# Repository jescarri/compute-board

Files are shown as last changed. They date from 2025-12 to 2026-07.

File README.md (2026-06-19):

# compute-board

This project is part of a template ecosystem for generating add-ons for my
custom esp32-powered compute boards.

It expects a 4-layer PCB with controlled impedance to 50 ohms.

<!-- KICAD_CI:START - Do not edit; auto-generated by .github/workflows/kicad-ci.yml -->



### Board preview

| Top | Bottom |
|---|---|
| top | bottom |

- [Schematic (PDF)](https://jescarri.github.io/compute-board/main/schematic/)
- [PCB layers (PDF)](https://jescarri.github.io/compute-board/main/pcb/)
- [STEP file](https://jescarri.github.io/compute-board/main/)
- [Full preview site](https://jescarri.github.io/compute-board/main/)

_Last updated from commit `0503de4` on 2026-06-19._
<!-- KICAD_CI:END -->

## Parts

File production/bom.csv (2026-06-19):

Designator | Footprint | Quantity | Value | LCSC Part #
C1 | 1206 | 1 | 100nF
C10, C11 | 1206 | 2 | 2.2uF
C2 | CP_EIA-3528-21_Kemet-B_HandSolder | 1 | 22uF
C3, C6 | 1206 | 2 | 10uF
C4, C8 | 1206 | 2 | 4.7uF
C5, C7 | 1206 | 2 | 1uF
C9 | 1206 | 1 | 0.1uF
D1 | LED_WS2812B-2020_PLCC4_2.0x2.0mm | 1 | WS2812B-2020
J1 | RHDR40W66P254_2X20_5146X500X1105P | 1 | PC104
J2 | TestPoint_Pad_2.0x2.0mm | 1 | ESP_PROG
J3 | JST_XH_B4B-XH-AM_1x04_P2.50mm_Vertical | 1 | ESP_PROGRAM
J4 | JST_XH_B4B-XH-AM_1x04_P2.50mm_Vertical | 1 | i2c
J5 | 1040310811 | 1 | 104031-0811
J6 | TestPoint_Pad_2.0x2.0mm | 1 | RST
R1, R2, R3, R4 | 1206 | 4 | 50k
R5, R6 | 1206 | 2 | 2.2K
R7, R8 | 1206 | 2 | 10K
RESET1 | SW_Push_1P1T_XKB_TS-1187A | 1 | RESET
SW1 | SW_Push_1P1T_XKB_TS-1187A | 1 | ESP Program
SW2 | SW_Push_1P1T_XKB_TS-1187A | 1 | WEB_CONF
U1 | ESP32-WROOM-32D | 1 | ESP32-WROOM-32E
U2, U4 | SOT-23-5 | 2 | XC6220B331MR
U3 | SOT-23 | 1 | TPS3839DBZ
V_BAT1 | Altech_AK300_1x02_P5.00mm_45-Degree | 1 | Conn_01x02

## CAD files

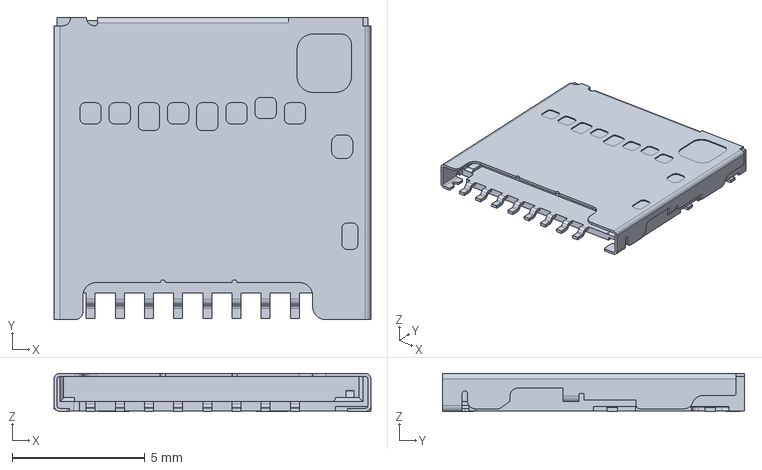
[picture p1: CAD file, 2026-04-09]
parts/3D/104031-0811.stp
11.9 x 11.4 x 1.45 mm

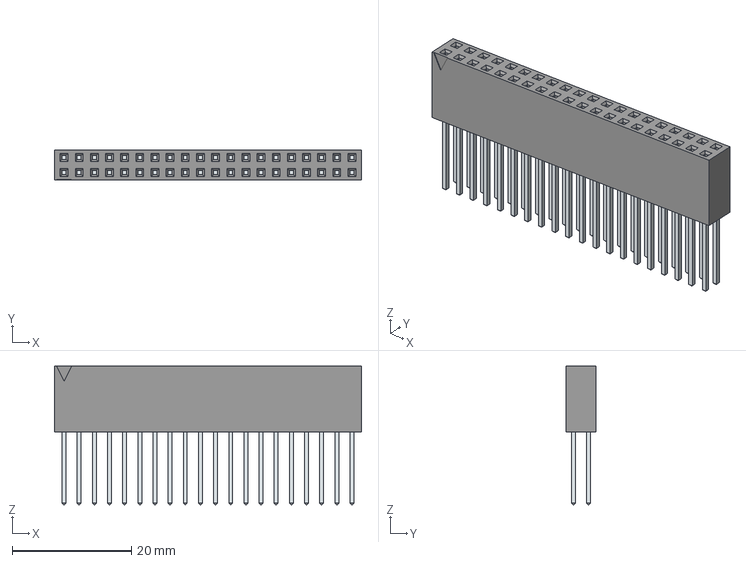
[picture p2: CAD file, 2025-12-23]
parts/3D/M20-6102045.stp
51.5 x 5.00 x 23.2 mm
LeadsArray

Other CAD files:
parts/3D/M20-6102045.stl

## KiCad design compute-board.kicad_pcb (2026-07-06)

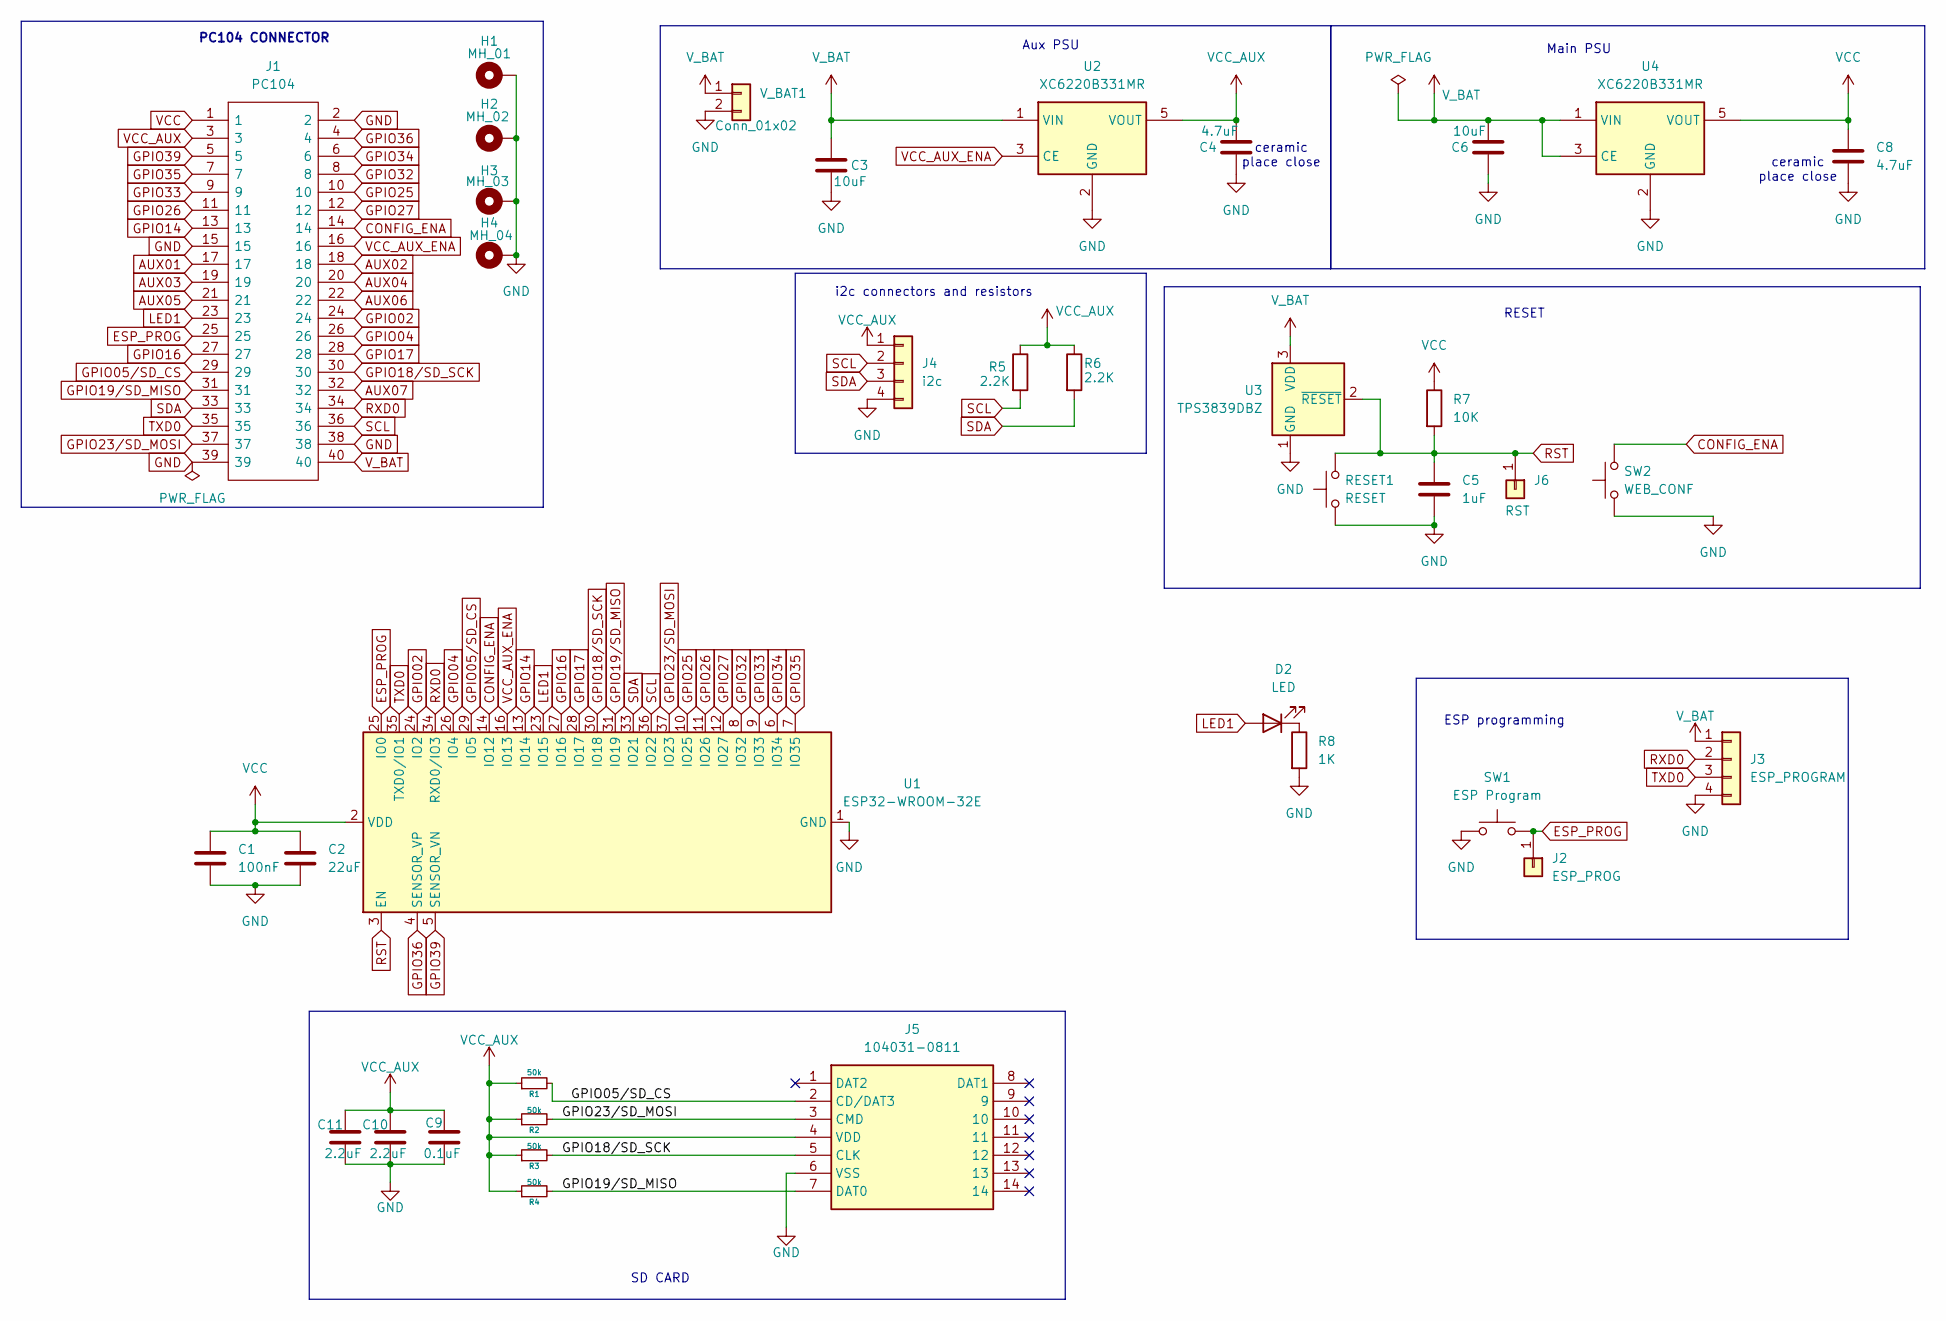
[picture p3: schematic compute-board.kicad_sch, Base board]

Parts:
C1: 100nF; C_1206_3216Metric_Pad1.33x1.80mm_HandSolder
C2: 22uF; CP_EIA-3528-21_Kemet-B_HandSolder
C3, C6: 10uF; C_1206_3216Metric_Pad1.33x1.80mm_HandSolder
C4, C8: 4.7uF; C_1206_3216Metric_Pad1.33x1.80mm_HandSolder
C5: 1uF; C_1206_3216Metric_Pad1.33x1.80mm_HandSolder
C9: 0.1uF; C_1206_3216Metric_Pad1.33x1.80mm_HandSolder
C10, C11: 2.2uF; C_1206_3216Metric_Pad1.33x1.80mm_HandSolder
D2: LED; LED_0603_1608Metric_Pad1.05x0.95mm_HandSolder
H1: MH_01; MountingHole_3.2mm_M3_ISO7380_Pad_TopBottom
H2: MH_02; MountingHole_3.2mm_M3_ISO7380_Pad_TopBottom
H3: MH_03; MountingHole_3.2mm_M3_ISO7380_Pad_TopBottom
H4: MH_04; MountingHole_3.2mm_M3_ISO7380_Pad_TopBottom
J1: PC104; RHDR40W66P254_2X20_5146X500X1105P; Manufacturer_Part_Number M20-6102045; Mouser Part Number 855-M20-6102045
J2: ESP_PROG; TestPoint_Pad_2.0x2.0mm
J3: ESP_PROGRAM; JST_XH_B4B-XH-AM_1x04_P2.50mm_Vertical
J4: i2c; JST_XH_B4B-XH-AM_1x04_P2.50mm_Vertical
J5: 104031-0811; 1040310811; Mouser Part Number 538-104031-0811
J6: RST; TestPoint_Pad_2.0x2.0mm
R1, R2, R3, R4: 50k; R_1206_3216Metric_Pad1.30x1.75mm_HandSolder
R5, R6: 2.2K; R_1206_3216Metric_Pad1.30x1.75mm_HandSolder
R7: 10K; R_1206_3216Metric_Pad1.30x1.75mm_HandSolder
R8: 1K; R_1206_3216Metric_Pad1.30x1.75mm_HandSolder
RESET1: RESET; SW_Push_1P1T_XKB_TS-1187A
SW1: ESP Program; SW_Push_1P1T_XKB_TS-1187A
SW2: WEB_CONF; SW_Push_1P1T_XKB_TS-1187A
U1: ESP32-WROOM-32E; ESP32-WROOM-32D
U2, U4: XC6220B331MR; SOT-23-5
U3: TPS3839DBZ; SOT-23
V_BAT1: Conn_01x02; Altech_AK300_1x02_P5.00mm_45-Degree

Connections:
AUX01: J1.17
AUX02: J1.18
AUX03: J1.19
AUX04: J1.20
AUX05: J1.21
AUX06: J1.22
AUX07: J1.32
CONFIG_ENA: J1.14, SW2.2, U1.14 (IO12)
ESP_PROG: J1.25, J2.1, SW1.2, U1.25 (IO0)
GND: C1.2, C2.2, C3.1, C4.2, C5.2, C6.2, C8.2, C9.2, C10.2, C11.2, H1.1, H2.1, H3.1, H4.1, J1.2, J1.15, J1.38, J1.39, J3.4, J4.4, J5.6 (VSS), R8.2, RESET1.1, SW1.1, SW2.1, U1.1 (GND), U1.15 (GND), U1.38 (GND), U1.39 (GND), U2.2 (GND), U3.1 (GND), U4.2 (GND), V_BAT1.2
GPIO02: J1.24, U1.24 (IO2)
GPIO04: J1.26, U1.26 (IO4)
GPIO05/SD_CS: J1.29, J5.2 (CD/DAT3), R1.2, U1.29 (IO5)
GPIO14: J1.13, U1.13 (IO14)
GPIO16: J1.27, U1.27 (IO16)
GPIO17: J1.28, U1.28 (IO17)
GPIO18/SD_SCK: J1.30, J5.5 (CLK), R3.2, U1.30 (IO18)
GPIO19/SD_MISO: J1.31, J5.7 (DAT0), R4.2, U1.31 (IO19)
GPIO23/SD_MOSI: J1.37, J5.3 (CMD), R2.2, U1.37 (IO23)
GPIO25: J1.10, U1.10 (IO25)
GPIO26: J1.11, U1.11 (IO26)
GPIO27: J1.12, U1.12 (IO27)
GPIO32: J1.8, U1.8 (IO32)
GPIO33: J1.9, U1.9 (IO33)
GPIO34: J1.6, U1.6 (IO34)
GPIO35: J1.7, U1.7 (IO35)
GPIO36: J1.4, U1.4 (SENSOR_VP)
GPIO39: J1.5, U1.5 (SENSOR_VN)
LED1: D2.2 (A), J1.23, U1.23 (IO15)
unnamed: D2.1 (K), R8.1
RST: C5.1, J6.1, R7.2, RESET1.2, U1.3 (EN), U3.2 (~RESET)
RXD0: J1.34, J3.2, U1.34 (RXD0/IO3)
SCL: J1.36, J4.2, R5.2, U1.36 (IO22)
SDA: J1.33, J4.3, R6.2, U1.33 (IO21)
TXD0: J1.35, J3.3, U1.35 (TXD0/IO1)
VCC: C1.1, C2.1, C8.1, J1.1, R7.1, U1.2 (VDD), U4.5 (VOUT)
VCC_AUX: C4.1, C9.1, C10.1, C11.1, J1.3, J4.1, J5.4 (VDD), R1.1, R2.1, R3.1, R4.1, R5.1, R6.1, U2.5 (VOUT)
VCC_AUX_ENA: J1.16, U1.16 (IO13), U2.3 (CE)
V_BAT: C3.2, C6.1, J1.40, J3.1, U2.1 (VIN), U3.3 (VDD), U4.1 (VIN), U4.3 (CE), V_BAT1.1

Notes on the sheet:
PC104 CONNECTOR
SD CARD
ceramic place close
ESP programming
Main PSU
RESET
Aux PSU
i2c connectors and resistors

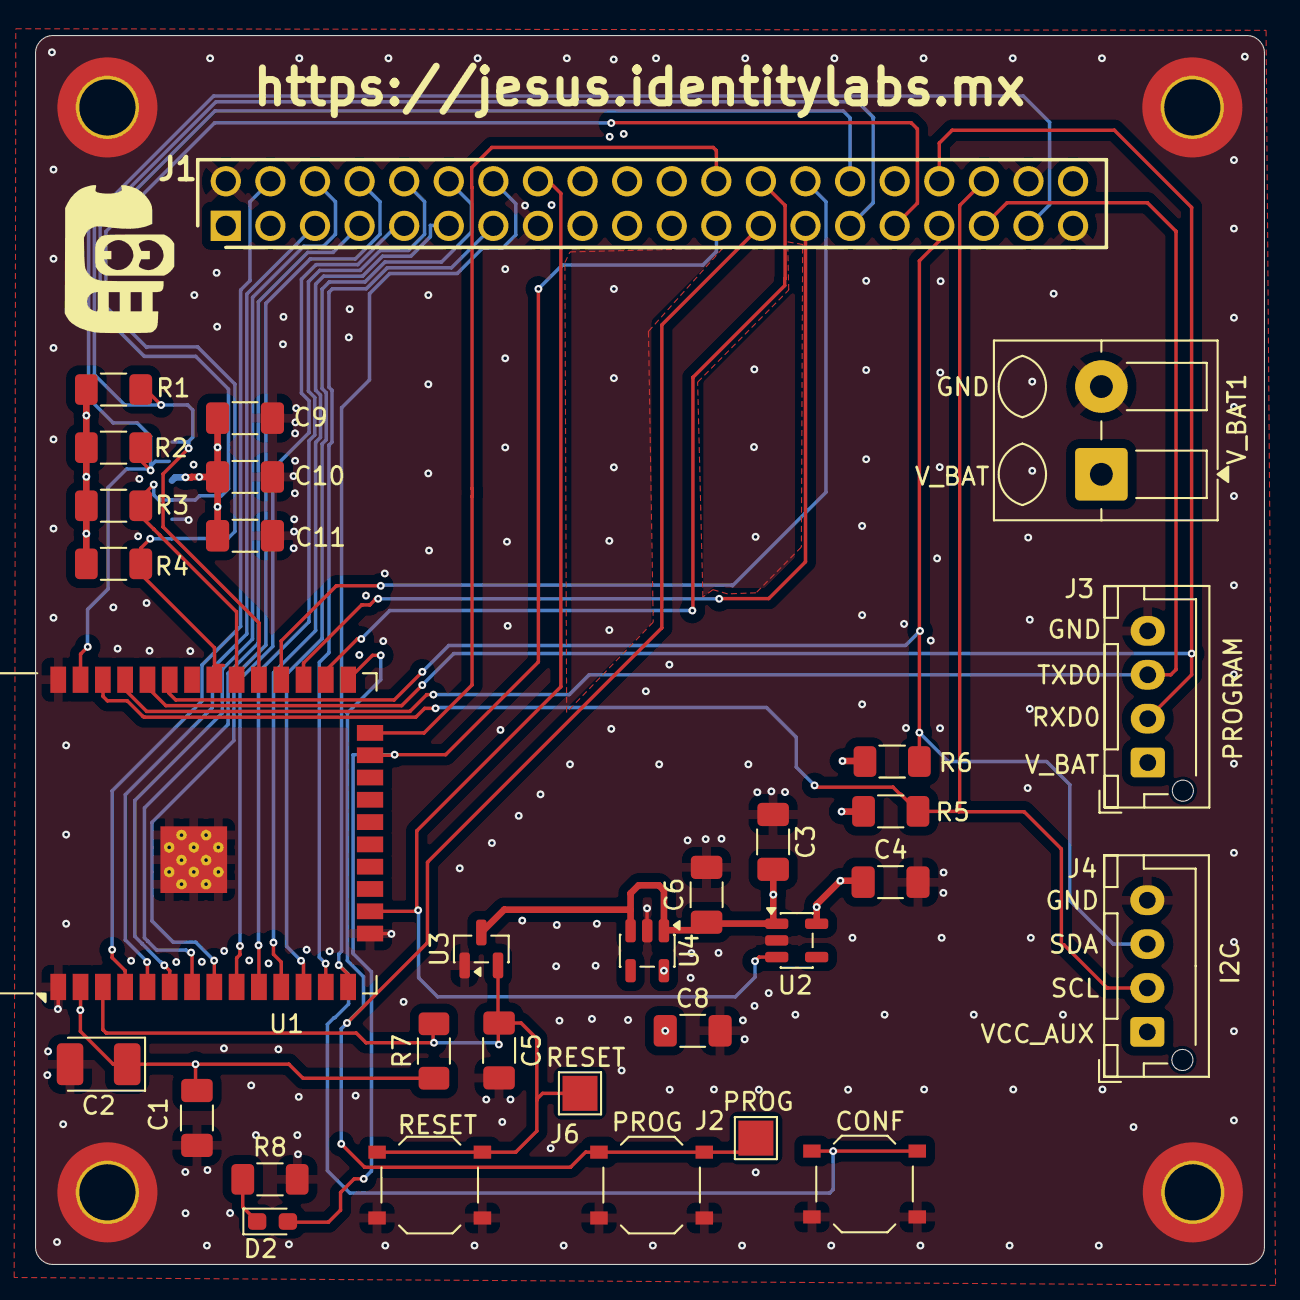
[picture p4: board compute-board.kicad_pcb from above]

Board: 4 copper layers, 70.0 x 70.0 mm, 37 parts (1 on the bottom side), 32 nets.

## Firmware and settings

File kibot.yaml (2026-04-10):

# KiBot configuration for compute-board
# Docs: https://kibot.readthedocs.io/
# This config drives the GitHub Actions workflow at .github/workflows/kicad-ci.yml.
# Edit here; CI will pick changes up automatically.

kibot:
  version: 1

global:
  # Emit KiBot's own per-run log into the output directory so it lands in the
  # published artifacts alongside the ERC/DRC reports.
  output: '%f-%i.%x'

preflight:
  run_erc: true
  run_drc: true
  check_zone_fills: true
  update_xml: true
  filters:
    # Library-table configuration warnings. The CI container does not share
    # the user's local KiCad global library tables, so any footprint/symbol
    # linked to a user-local library fires these. Not a real ERC/DRC issue;
    # silenced so the preflight reports meaningful board state.
    - filter: 'lib_footprint_issues (library config, not a real DRC issue)'
      error: 'lib_footprint_issues'
      regex: '.*'
    - filter: 'footprint_link_issues (library config, ERC variant)'
      error: 'footprint_link_issues'
      regex: '.*'
    # Cosmetic: silkscreen clipped by board outline. Review on the next
    # board spin; not a functional defect.
    - filter: 'silk_edge_clearance (cosmetic, review manually)'
      error: 'silk_edge_clearance'
      regex: '.*'

outputs:
  # ERC and DRC reports are produced by the preflight above as plain-text
  # files at the out/ root (compute-board-erc.txt, compute-board-drc.txt).
  # parse-reports.sh reads those; no explicit erc/drc output types exist
  # in KiBot 1.8.5.

  # ---------- Schematic ----------
  - name: schematic_pdf
    comment: 'Schematic (PDF)'
    type: pdf_sch_print
    dir: schematic
    options:
      output: '%f-schematic.pdf'

  - name: schematic_svg
    comment: 'Schematic (SVG)'
    type: svg_sch_print
    dir: schematic
    options:
      output: '%f-schematic.svg'

  # ---------- PCB layers (single PDF, one sheet per layer view) ----------
  - name: pcb_print_pdf
    comment: 'PCB layers (PDF)'
    type: pcb_print
    dir: pcb
    options:
      output: '%f-pcb.pdf'
      format: PDF
      pages:
        - sheet: 'Front composite'
          layers:
            - layer: F.Cu
            - layer: F.Silkscreen
            - layer: F.Mask
            - layer: Edge.Cuts
        - sheet: 'Back composite'
          layers:
            - layer: B.Cu
            - layer: B.Silkscreen
            - layer: B.Mask
            - layer: Edge.Cuts
        - sheet: 'F.Cu'
          layers:
            - layer: F.Cu
            - layer: Edge.Cuts
        - sheet: 'In1.Cu'
          layers:
            - layer: In1.Cu
            - layer: Edge.Cuts
        - sheet: 'In2.Cu'
          layers:
            - layer: In2.Cu
            - layer: Edge.Cuts
        - sheet: 'B.Cu'
          layers:
            - layer: B.Cu
            - layer: Edge.Cuts
        - sheet: 'F.Silkscreen'
          layers:
            - layer: F.Silkscreen
            - layer: Edge.Cuts
        - sheet: 'B.Silkscreen'
          layers:
            - layer: B.Silkscreen
            - layer: Edge.Cuts
        - sheet: 'Edge.Cuts'
          layers:
            - layer: Edge.Cuts

  # ---------- Stylised board images (PcbDraw) ----------
  - name: pcbdraw_front
    comment: 'PCB front (PcbDraw)'
    type: pcbdraw
    dir: pcb
    options:
      format: png
      dpi: 300
      output: '%f-pcbdraw-front.png'

  - name: pcbdraw_back
    comment: 'PCB back (PcbDraw)'
    type: pcbdraw
    dir: pcb
    options:
      format: png
      dpi: 300
      bottom: true
      output: '%f-pcbdraw-back.png'

  # ---------- 3D renders (ray-traced top, fast bottom + iso) ----------
  # auto_crop trims empty background so the board fills the image without
  # needing a zoom factor. Leaving zoom unset uses the default "fit to
  # viewport" behaviour; setting zoom > 1 clips the board (see git history).
  - name: render_3d_top
    comment: '3D render - top (ray-traced)'
    type: render_3d
    dir: 3d
    options:
      output: top.png
      ray_tracing: true
      width: 1600
      height: 1200
      view: top
      auto_crop: true

  - name: render_3d_bottom
    comment: '3D render - bottom'
    type: render_3d
    dir: 3d
    options:
      output: bottom.png
      width: 1600
      height: 1200
      view: bottom
      auto_crop: true

  - name: render_3d_iso
    comment: '3D render - iso view'
    type: render_3d
    dir: 3d
    options:
      output: iso.png
      width: 1600
      height: 1200
      rotate_x: 3  # units of 10deg -> 30deg
      rotate_z: -2 # -20deg
      auto_crop: true

  # ---------- STEP (mechanical handoff) ----------
  - name: step
    comment: 'STEP file'
    type: step
    dir: '.'
    options:
      output: '%f.step'

  # ---------- Structured ERC/DRC report (markdown + data) ----------
  - name: report
    comment: 'Project report'
    type: report
    dir: reports
    options:
      output: '%f-report.txt'
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

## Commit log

2026-04-10 ci: add KiBot workflow with GitHub Pages previews and PR comments
    Runs ERC/DRC, renders schematic, PCB layers, and 3D views on every PR
    and push to main. Publishes per-PR previews to gh-pages/pr-<N>/<sha>/
    and the latest main build to gh-pages/main/, then posts a sticky PR
    comment with ERC/DRC status, the 3D top render, and links to the full
    preview site. Main builds additionally rewrite an auto-managed block
    in README.md so the default branch always shows the current renders.
2026-04-10 FIX: routing recommendations
    [compute-board.kicad_pcb]
2026-04-10 ci(kibot): filter library-config warnings and add ERC/DRC report outputs
    The DRC preflight was failing with 5 "violations" on CI: 4 lib_footprint_issues
    warnings (the CI container does not share the user's local KiCad library
    tables, so any footprint linked to a user-local lib fires this) plus 1
    cosmetic silk_edge_clearance warning. KiBot's run_drc treats warnings as hard
    failures by default, so the job failed despite the board being clean.
    Add preflight.filters entries to silence the two library-config codes (not
    real issues) and the silk warning (cosmetic, reviewable manually), with
    comments explaining why each is filtered.
    Also add explicit erc/drc output types targeting reports/. The p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
    [kibot.yaml]
2026-04-10 ci: parse ERC/DRC from KiBot's plain-text reports
    KiBot 1.8.5 has no erc/drc output types; the previous commit's attempt
    to declare them as outputs made the whole KiBot run abort with "Unknown
    output type: erc" before producing anything. Drop the bogus outputs and
    parse the plain-text reports KiBot writes by default at the out/ root
    (compute-board-erc.txt, compute-board-drc.txt).
    Rewrite parse-reports.sh to count " ; error" / " ; warning"
    severity lines in those files with awk instead of jq. Filtered
    violations (see preflight.filters) do not appear in these files, so
    the counts reflect post-filter state, which is what the badges and
    PR comment want.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
    [kibot.yaml]
2026-04-10 ci: fix landing-index skip and honest DRC/ERC counts
    Three fixes uncovered on the first end-to-end run:
    1. landing / pr-cleanup commit steps used `git diff --quiet` to decide
    whether to commit, which does not detect untracked new files. On the
    first run this caused the freshly-written index.html to be silently
    dropped. Stage first, then check `git diff --cached --quiet`.
    2. parse-reports.sh previously counted every violation in the KiBot
    TXT reports. KiBot's preflight filters prevent the preflight from
    aborting but do not strip violations from the RPT output, so the
    badge showed the pre-filter count (e.g. DRC 0/5) even though the
    preflight passed. Post-filter the libra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
2026-04-10 ci: uncropped 3D renders, fixed PR-comment links, add PCB layer images
    3D renders had zoom:3 which clipped the board well inside the
    viewport. Drop it and add auto_crop:true so each render trims empty
    background to fit the board.
    The old PR comment linked to directories (e.g. schematic/) which 404
    on GitHub Pages since directory listing is not served. Link to the
    actual file paths matching kibot.yaml's dir/output settings, and add
    inline PcbDraw front/back renders so reviewers see the top and bottom
    copper/silk without opening the PDF.
    [kibot.yaml]
2026-04-10 UPDATE: schematic and pcb revision
    [compute-board.kicad_pcb, compute-board.kicad_sch]
2026-04-10 FIX: bottom skilscreen
    [compute-board.kicad_pcb]
2026-04-10 ci: keep closed-PR previews and add PCB/schematic diff vs main
    Issue 1: merging a PR ran pr-cleanup.yml which deleted pr-<N>/ from
    gh-pages, silently breaking every image in the (now closed) PR's
    sticky comment. Remove the cleanup workflow and its helper script.
    Closed-PR preview trees now accumulate on gh-pages, which is the
    right tradeoff: the historical comments stay valid and the disk cost
    is tiny compared to the review-history value. If gh-pages ever grows
    unwieldy a periodic prune can be added later as an opt-in job.
    Issue 2: no diff view. Add KiBot `diff` outputs (type: diff) that
    compare the current working copy against origin/main -- one for the
    PCB (per-layer red/green overlay PDF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
    [kibot.yaml]
2026-04-10 chore: untrack .claude/settings.local.json
    The file was committed before .gitignore listed it, so .gitignore had
    no effect (it only filters untracked paths). Remove from the index so
    local Claude Code permission edits stop showing up in git status.
2026-05-28 fix(ci): use KiBot 1.9.0 correct flags for target inversion
    KiBot 1.9.0 does not have --invert-sel or --target flags.
    The correct syntax is -i (short only) with target names as
    positional arguments. This caused every main-branch push to
    fail immediately with a usage/help printout and exit 1.
    The PR trigger was unaffected because it passes additional_args=' '
    with no invert logic at all.
2026-06-19 ADD: bom
    [bom.csv]
2026-07-06 (fix): various hardware designgs issues.
    1. Add thermal reliefs.
    2. Remove Pullup on CONFIG button, this was causing the esp32 to select
    1.8v FLASH.
    3. Replace addresable led with a single color led.
    [compute-board.kicad_pcb, compute-board.kicad_sch]
